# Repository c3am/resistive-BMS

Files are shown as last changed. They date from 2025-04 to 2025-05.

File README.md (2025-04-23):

This is a low cost 4s BMS (battery management system) based on the ch32v003 microcontroller.
features:
- Cell voltage measurement using an ads1115 16bit adc
- high side bidirectional current sensing using the ina181a2 current sense amplifier
- charge/discharge enable using low side mosfets
- 20Ohm resistive balancing (-> 200mA at 4V -> 0.8W)
- I/O: 1x Uart, 1x SWIO (for programming)

This BMS is still under development and I haven't even tested it yet.

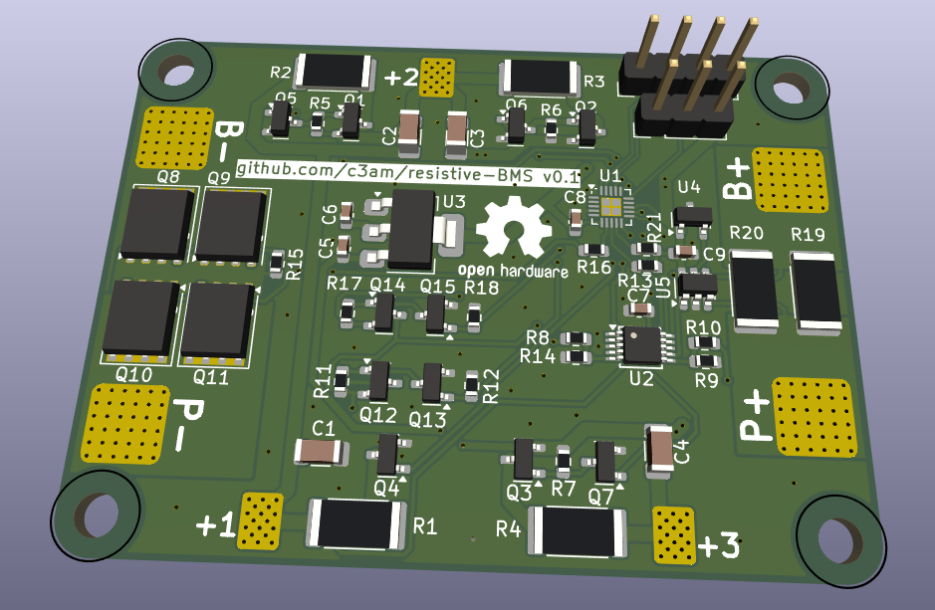
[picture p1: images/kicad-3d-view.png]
the kicad 3d view of the 4s BMS board

the schematic of the board

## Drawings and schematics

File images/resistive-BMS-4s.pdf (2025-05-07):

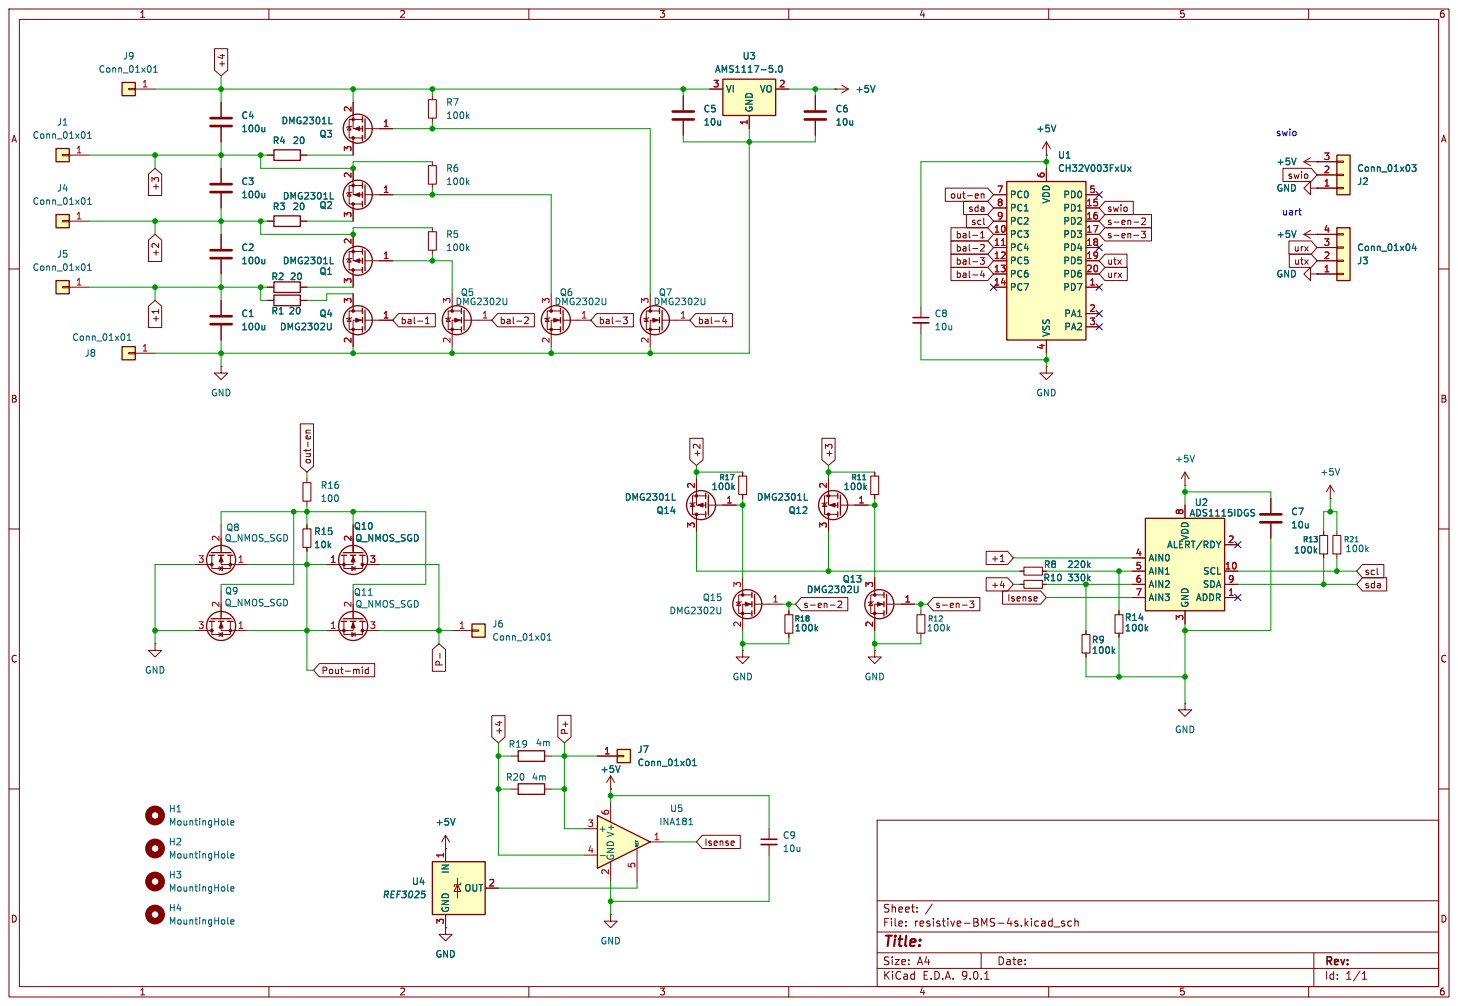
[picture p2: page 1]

utx bal-1 Pout-mid

3 ALERT/RDY 2 SCL 10 SDA 9 ADDR 1 U2 ADS1115IDGS H3 MountingHole H4 MountingHole H2 MountingHole H1 MountingHole GND

3 ALERT/RDY 2 SCL 10 SDA 9 ADDR 1 R14

Id: 1/1 Title: File: resistive-BMS-4s.kicad_sch Sheet: /

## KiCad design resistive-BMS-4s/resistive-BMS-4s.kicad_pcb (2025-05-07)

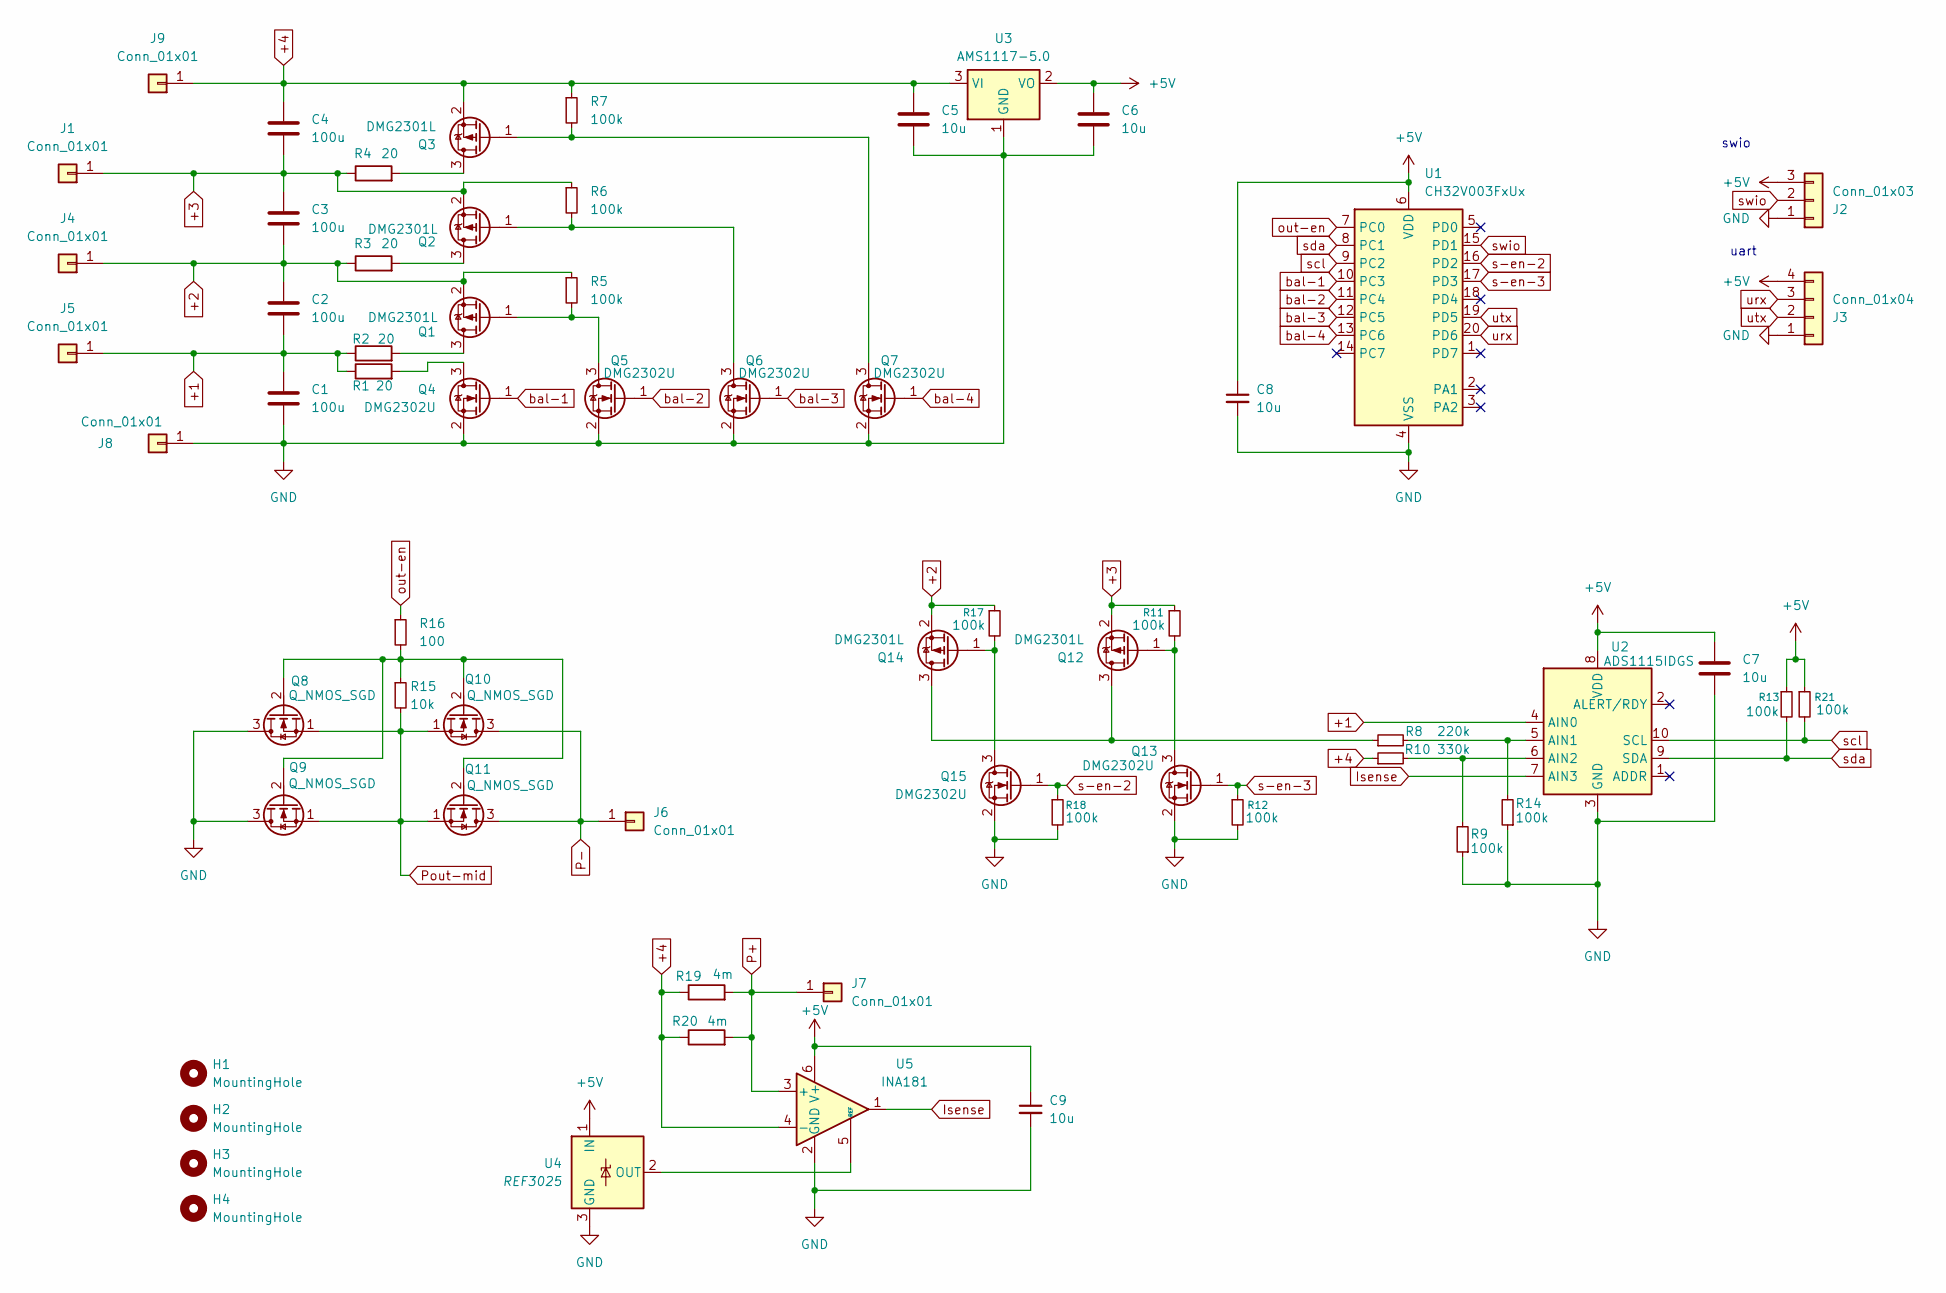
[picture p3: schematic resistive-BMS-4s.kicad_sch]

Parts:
C1, C2, C3, C4: 100u; C_1206_3216Metric
C5, C6, C7, C8, C9: 10u; C_0603_1608Metric
H1, H2, H3, H4: MountingHole; MountingHole_3.2mm_M3
J1, J4, J5: Conn_01x01; pad-4x3mm
J2: Conn_01x03; PinHeader_1x03_P2.54mm_Vertical
J3: Conn_01x04; PinHeader_1x04_P2.54mm_Vertical
J6, J7, J8, J9: Conn_01x01; pad-6x6mm
Q1, Q2, Q3, Q12, Q14: DMG2301L; SOT-23
Q4, Q5, Q6, Q7, Q13, Q15: DMG2302U; SOT-23
Q8, Q9, Q10, Q11: Q_NMOS_SGD; PQFN-8-EP_6x5mm_P1.27mm_Generic
R1, R2, R3, R4: 20; R_2512_6332Metric
R5, R6, R7, R9, R11, R12, R13, R14, R17, R18, R21: 100k; R_0603_1608Metric
R8: 220k; R_0603_1608Metric
R10: 330k; R_0603_1608Metric
R15: 10k; R_0603_1608Metric
R16: 100; R_0603_1608Metric
R19, R20: 4m; R_2512_6332Metric
U1: CH32V003FxUx; QFN-20-1EP_3x3mm_P0.4mm_EP1.65x1.65mm
U2: ADS1115IDGS; TSSOP-10_3x3mm_P0.5mm
U3: AMS1117-5.0; SOT-223-3_TabPin2
U4: REF3025; SOT-23
U5: INA181; SOT-23-6

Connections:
+1: C1.1, C2.2, J5.1, R1.1, R2.1, U2.4 (AIN0)
+2: C2.1, C3.2, J4.1, Q1.2 (S), Q14.2 (S), R3.1, R5.1, R17.1
+3: C3.1, C4.2, J1.1, Q2.2 (S), Q12.2 (S), R4.1, R6.1, R11.1
+4: C4.1, C5.1, J9.1, Q3.2 (S), R7.1, R10.1, R19.1, R20.1, U3.3 (VI), U5.4 (-)
+5V: C6.1, C7.1, C8.1, C9.1, J2.3, J3.4, R13.1, R21.1, U1.6 (VDD), U2.8 (VDD), U3.2 (VO), U4.1 (IN), U5.6 (V+)
GND: C1.2, C5.2, C6.2, C7.2, C8.2, C9.2, J2.1, J3.1, J8.1, Q4.2 (S), Q5.2 (S), Q6.2 (S), Q7.2 (S), Q8.3 (D), Q9.3 (D), Q13.2 (S), Q15.2 (S), R9.1, R12.2, R14.1, R18.2, U1.4 (VSS), U1.21 (VSS), U2.3 (GND), U3.1 (GND), U4.3 (GND), U5.2 (GND)
Isense: U2.7 (AIN3), U5.1
unnamed: Q1.3 (D), R2.2
unnamed: Q1.1 (G), Q5.3 (D), R5.2
unnamed: Q2.3 (D), R3.2
unnamed: Q2.1 (G), Q6.3 (D), R6.2
unnamed: Q3.3 (D), R4.2
unnamed: Q3.1 (G), Q7.3 (D), R7.2
unnamed: Q4.3 (D), R1.2
unnamed: Q8.2 (G), Q9.2 (G), Q10.2 (G), Q11.2 (G), R15.1, R16.2
unnamed: Q12.3 (D), Q14.3 (D), R8.1
unnamed: Q12.1 (G), Q13.3 (D), R11.2
unnamed: Q14.1 (G), Q15.3 (D), R17.2
unnamed: R8.2, R14.2, U2.5 (AIN1)
unnamed: R9.2, R10.2, U2.6 (AIN2)
unnamed: U4.2 (OUT), U5.5 (REF)
P+: J7.1, R19.2, R20.2, U5.3 (+)
P-: J6.1, Q10.3 (D), Q11.3 (D)
Pout-mid: Q8.1 (S), Q9.1 (S), Q10.1 (S), Q11.1 (S), R15.2
bal-1: Q4.1 (G), U1.10 (PC3)
bal-2: Q5.1 (G), U1.11 (PC4)
bal-3: Q6.1 (G), U1.12 (PC5)
bal-4: Q7.1 (G), U1.13 (PC6)
out-en: R16.1, U1.7 (PC0)
s-en-2: Q15.1 (G), R18.1, U1.16 (PD2)
s-en-3: Q13.1 (G), R12.1, U1.17 (PD3)
scl: R21.2, U1.9 (PC2), U2.10 (SCL)
sda: R13.2, U1.8 (PC1), U2.9 (SDA)
swio: J2.2, U1.15 (PD1)
urx: J3.3, U1.20 (PD6)
utx: J3.2, U1.19 (PD5)

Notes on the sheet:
uart
swio

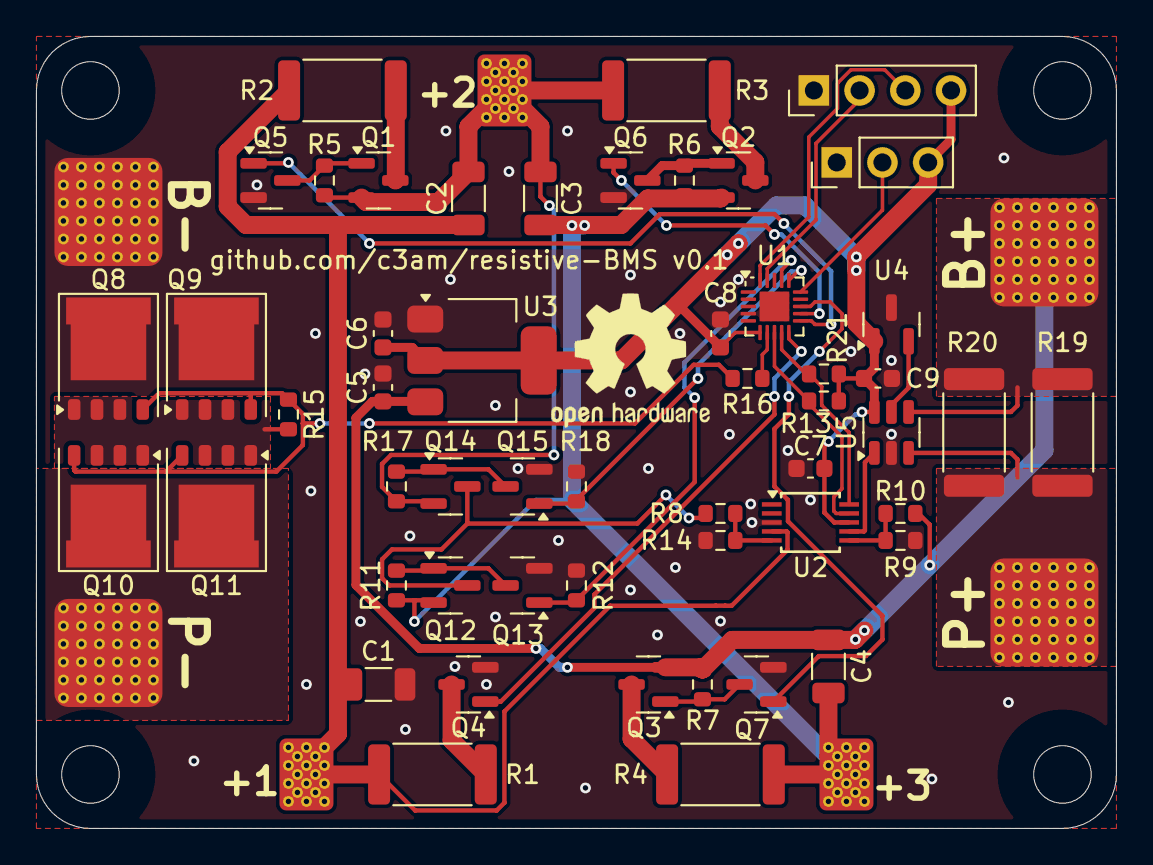
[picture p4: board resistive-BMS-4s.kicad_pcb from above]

Board: 2 copper layers, 60.0 x 44.0 mm, 63 parts (0 on the bottom side), 36 nets.

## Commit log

2025-04-23 readme added
    [resistive-BMS-4s.kicad_pcb]
2025-04-23 added images
    [resistive-BMS-4s.kicad_pcb]
2025-04-23 added value to decoupling capacitor
    [resistive-BMS-4s.kicad_sch]
2025-04-23 added silkscreen labels to pads
    [resistive-BMS-4s.kicad_pcb]
2025-05-07 version 0.1
    [resistive-BMS-4s.kicad_pcb, resistive-BMS-4s.kicad_sch]
2025-05-07 added fabrication output files
    [resistive-BMS-4s-B_Cu.gbl, resistive-BMS-4s-B_Mask.gbs, resistive-BMS-4s-B_Paste.gbp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]
